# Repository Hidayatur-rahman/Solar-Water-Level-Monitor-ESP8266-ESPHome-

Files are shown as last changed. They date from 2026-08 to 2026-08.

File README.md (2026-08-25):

# Solar Water Level Monitor (ESP8266 + ESPHome)

A solar-powered water tank level monitoring system built around the ESP8266 (ESP-12E), designed in KiCad and running on ESPHome. It measures water level with an ultrasonic sensor, monitors battery current/voltage, and charges itself from a solar panel with a selectable-voltage MPPT charger.

## Features

- **Water level sensing** using an HC-SR04 ultrasonic distance sensor
- **Solar MPPT charging** via CN3791, with jumper-selectable input voltage (6V / 9V / 12V)
- **Battery current & voltage monitoring** using an INA219 sensor
- **1S Li-ion protection** (over-charge / over-discharge / over-current) using DW01A + FS8205A
- **5V boost converter** (MT3608) to power the ESP8266 and sensors from a single Li-ion cell
- **Deep sleep support** for low power consumption between readings
- **ESPHome integration** — no custom firmware needed, works directly with Home Assistant

## Hardware Overview


 




| Block | Component | Notes |
|---|---|---|
| MCU | ESP-12E (ESP8266) | Runs ESPHome |
| Water sensor | HC-SR04 | 5V supply, echo signal stepped down to 3.3V via voltage divider |
| Current/voltage sensor | INA219 | I2C, monitors battery current (charge & discharge) |
| Boost converter | MT3608 | Steps battery voltage (3.0–4.2V) up to 5V |
| Solar charger | CN3791 | MPPT buck charger, up to 4A, input jumper-selectable for 6V/9V/12V panels |
| Battery protection | DW01A + FS8205A | Standard 1S Li-ion protection circuit |
| Battery | 1x 18650 Li-ion | Not included on the board |

## Pin Connections (ESP-12E)

| Function | GPIO |
|---|---|
| I2C SDA (INA219) | GPIO4 |
| I2C SCL (INA219) | GPIO5 |
| HC-SR04 Trig | GPIO14 |
| HC-SR04 Echo (via divider) | GPIO12 |
| Deep sleep wake | GPIO16 → RST (via solder jumper) |

## Solar Panel Voltage Selection

The CN3791 MPPT tracking voltage is set by closing one solder jumper on the board.
| Panel | Target MPPT | R18  | | VMPPT |
| --- | ---: | ---: | ---: | ---: |
| **6 V**  | ~5,0 V | 200k | **68k** |  **4,75 V** |
| **9 V**  | ~8,0 V | 200k | **39k** |  **7,38 V** |
| **12 V** | ~10,2 V | 200k | **33k** |  **8,50 V** |

> Only close **one** jumper at a time.

## Getting Started

1. Flash the board with [ESPHome](https://esphome.io/), using the provided YAML configuration (`esphome/water-level-sensor.yaml`)
2. Connect the HC-SR04, battery, and solar panel
3. Set the solar jumper according to your panel's voltage
4. Add the device to Home Assistant via the ESPHome integration

## PCB

- Designed in KiCad, 2-layer, 60x60mm
- Gerber files and schematic are in the `/hardware` folder

## License

MIT — feel free to use, modify, and build upon this project.

## Disclaimer

This is a hobbyist/DIY project. Double-check battery polarity and solar jumper settings before powering on. No warranty is provided — build and use at your own risk.

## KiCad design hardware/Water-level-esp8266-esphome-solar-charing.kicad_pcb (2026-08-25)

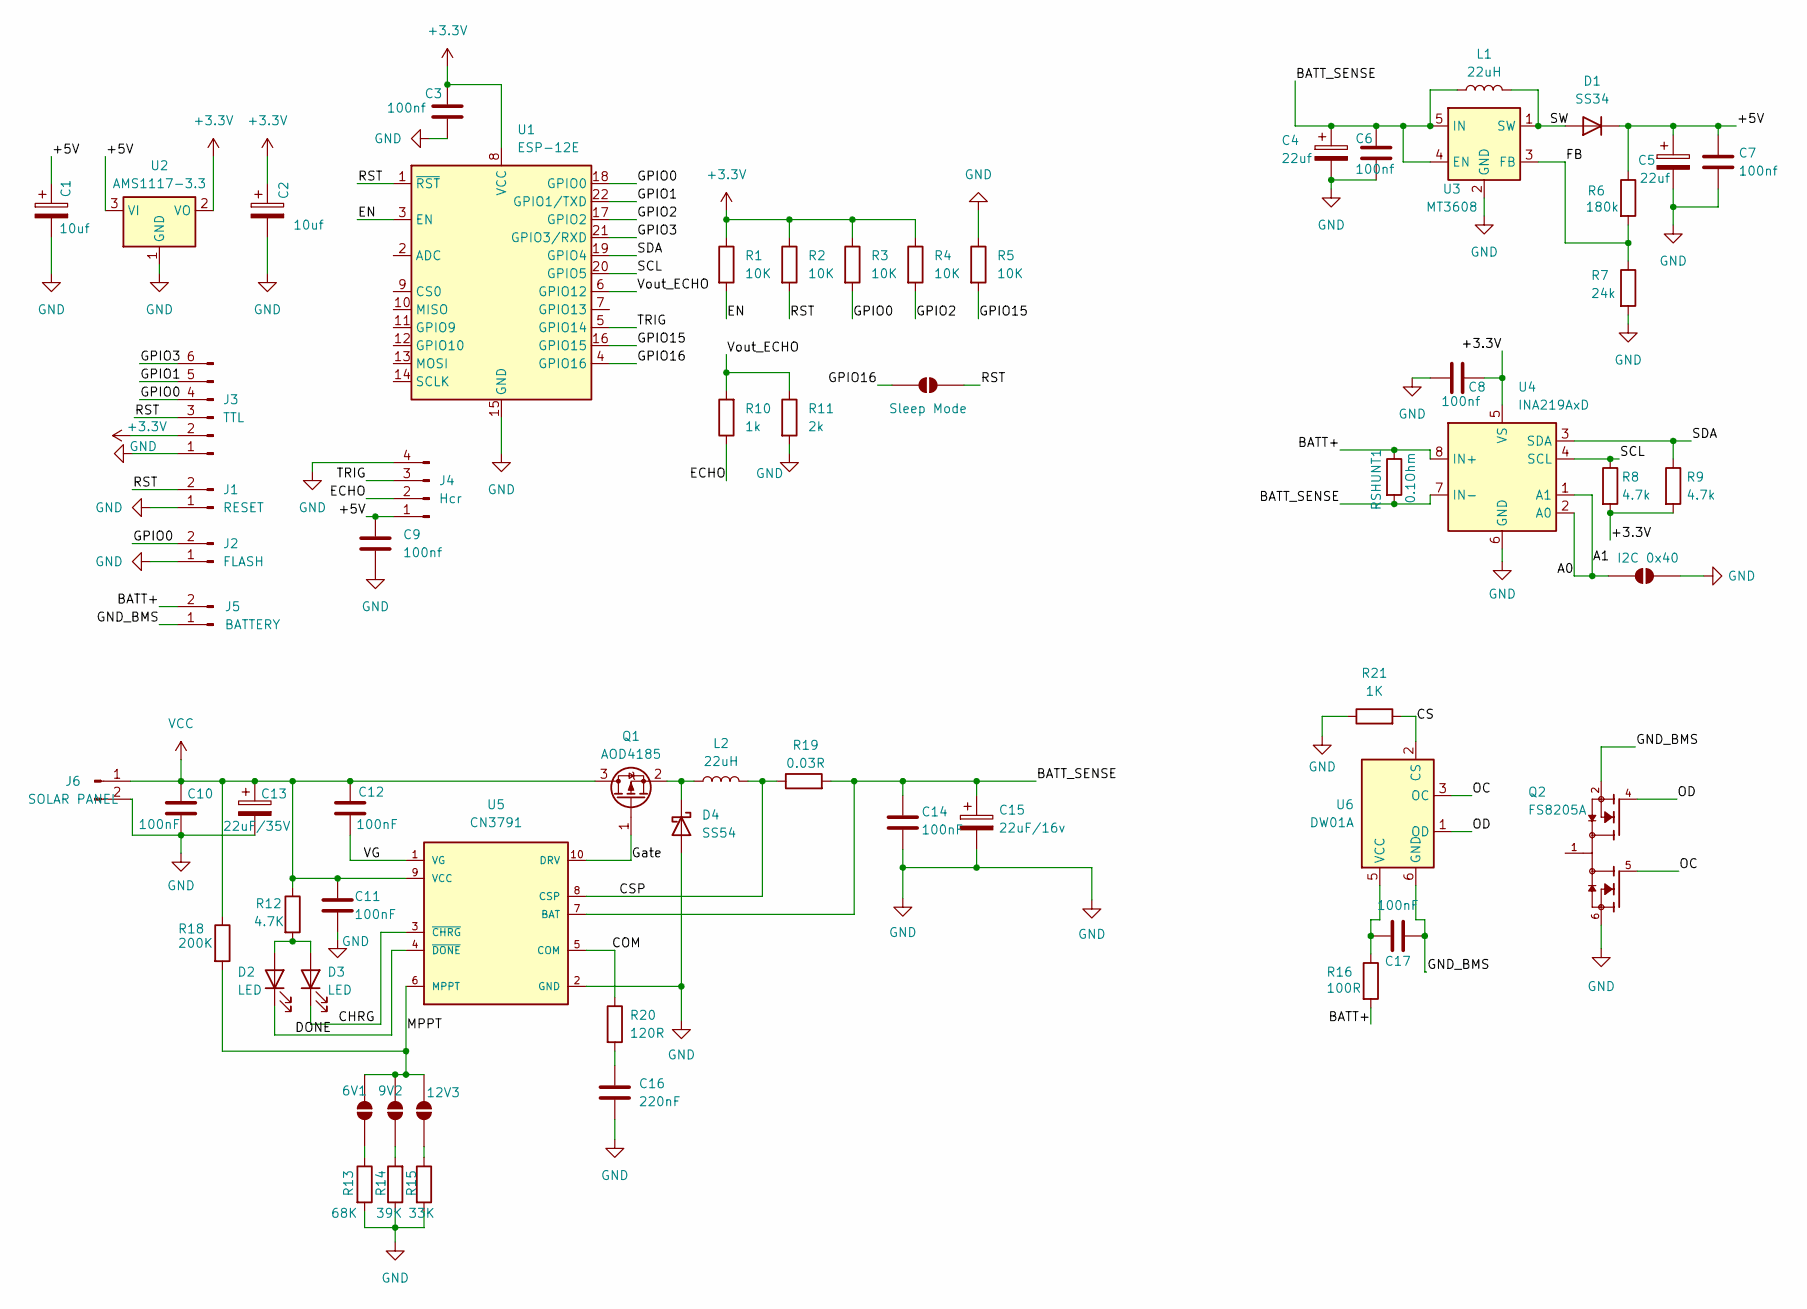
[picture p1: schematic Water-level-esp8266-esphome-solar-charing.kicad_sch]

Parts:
6V1, 9V2, 12V3: SolderJumper_2_Open; SolderJumper-2_P1.3mm_Open_RoundedPad1.0x1.5mm
C1, C2: 10uf; C_1206_3216Metric_Pad1.33x1.80mm_HandSolder
C3, C6, C7, C8, C9: 100nf; C_0603_1608Metric_Pad1.08x0.95mm_HandSolder
C4, C5: 22uf; C_1206_3216Metric_Pad1.33x1.80mm_HandSolder
C10, C11, C12, C14, C17: 100nF; C_0603_1608Metric_Pad1.08x0.95mm_HandSolder
C13: 22uF/35V; CP_Elec_8x6.9
C15: 22uF/16v; CP_Elec_8x6.9
C16: 220nF; C_0603_1608Metric_Pad1.08x0.95mm_HandSolder
D1: SS34; D_1206_3216Metric_Pad1.42x1.75mm_HandSolder
D2, D3: LED; LED_0805_2012Metric_Pad1.15x1.40mm_HandSolder
D4: SS54; D_SMA
J1: RESET; PinHeader_1x02_P2.54mm_Vertical
J2: FLASH; PinHeader_1x02_P2.54mm_Vertical
J3: TTL; PinHeader_1x06_P2.54mm_Vertical
J4: Hcr; PinHeader_1x04_P2.54mm_Vertical
J5: BATTERY; JST_PH_B2B-PH-K_1x02_P2.00mm_Vertical
J6: SOLAR PANEL; JST_PH_B2B-PH-K_1x02_P2.00mm_Vertical
JP1: Sleep Mode; SolderJumper-2_P1.3mm_Open_Pad1.0x1.5mm
JP2: I2C 0x40; SolderJumper-2_P1.3mm_Open_Pad1.0x1.5mm
L1: 22uH; L_Changjiang_FNR4030S
L2: 22uH; L_Changjiang_FXL1030
Q1: AOD4185; TO-252-2
Q2: FS8205A; SOP65P640X120-8N; PARTREV 1.7
R1, R2, R3, R4, R5: 10K; R_0805_2012Metric_Pad1.20x1.40mm_HandSolder
R6: 180k; R_0805_2012Metric_Pad1.20x1.40mm_HandSolder
R7: 24k; R_0805_2012Metric_Pad1.20x1.40mm_HandSolder
R8, R9: 4.7k; R_0805_2012Metric_Pad1.20x1.40mm_HandSolder
R10: 1k; R_0805_2012Metric_Pad1.20x1.40mm_HandSolder
R11: 2k; R_0805_2012Metric_Pad1.20x1.40mm_HandSolder
R12: 4.7K; R_0805_2012Metric_Pad1.20x1.40mm_HandSolder
R13: 68K; R_0805_2012Metric_Pad1.20x1.40mm_HandSolder
R14: 39K; R_0805_2012Metric_Pad1.20x1.40mm_HandSolder
R15: 33K; R_0805_2012Metric_Pad1.20x1.40mm_HandSolder
R16: 100R; R_0805_2012Metric_Pad1.20x1.40mm_HandSolder
R18: 200K; R_0805_2012Metric_Pad1.20x1.40mm_HandSolder
R19: 0.03R; R_2512_6332Metric_Pad1.40x3.35mm_HandSolder
R20: 120R; R_0805_2012Metric_Pad1.20x1.40mm_HandSolder
R21: 1K; R_0805_2012Metric_Pad1.20x1.40mm_HandSolder
RSHUNT1: 0.1Ohm; R_2512_6332Metric_Pad1.40x3.35mm_HandSolder
U1: ESP-12E
U2: AMS1117-3.3; SOT-223-3_TabPin2
U3: MT3608; SOT-23-6
U4: INA219AxD; SOIC-8_3.9x4.9mm_P1.27mm
U5: CN3791; CN3791_SSOP10
U6: DW01A; SOT-23-6

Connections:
+3.3V: C2.1, C3.1, C8.2, J3.2, R1.1, R2.1, R3.1, R4.1, R8.2, R9.2, U1.8 (VCC), U2.2 (VO), U4.5 (VS)
/+5V: C1.1, C5.1, C7.1, C9.1, D1.1 (K), J4.1, R6.1, U2.3 (VI)
/A0: JP2.2 (B), U4.1 (A1), U4.2 (A0)
/BATT+: J5.2, R16.2, RSHUNT1.1, U4.8 (IN+)
/BATT_SENSE: C4.1, C6.1, C14.1, C15.1, L1.1, R19.2, RSHUNT1.2, U3.4 (EN), U3.5 (IN), U4.7 (IN-), U5.7 (BAT)
/CHRG: D3.1 (K), U5.3 (~CHRG)
/COM: R20.1, U5.5 (COM)
/CS: R21.2, U6.2 (CS)
/CSP: L2.2, R19.1, U5.8 (CSP)
/DONE: D2.1 (K), U5.4 (~DONE)
/ECHO: J4.2, R10.1
/EN: R1.2, U1.3 (EN)
/FB: R6.2, R7.1, U3.3 (FB)
/GND_BMS: C17.2, J5.1, Q2.2, Q2.3, U6.6 (GND)
/GPIO0: J2.2, J3.4, R3.2, U1.18 (GPIO0)
/GPIO1: J3.5, U1.22 (GPIO1/TXD)
/GPIO2: R4.2, U1.17 (GPIO2)
/GPIO3: J3.6, U1.21 (GPIO3/RXD)
/GPIO15: R5.2, U1.16 (GPIO15)
/GPIO16: JP1.2 (B), U1.4 (GPIO16)
/Gate: Q1.1 (G), U5.10 (DRV)
/MPPT: 6V1.2 (B), 9V2.1 (A), 12V3.2 (B), R18.2, U5.6 (MPPT)
/OC: Q2.5, U6.3 (OC)
/OD: Q2.4, U6.1 (OD)
/RST: J1.2, J3.3, JP1.1 (A), R2.2, U1.1 (~RST)
/SCL: R8.1, U1.20 (GPIO5), U4.4 (SCL)
/SDA: R9.1, U1.19 (GPIO4), U4.3 (SDA)
/SW: D1.2 (A), L1.2, U3.1 (SW)
/TRIG: J4.3, U1.5 (GPIO14)
/VG: C12.2, U5.1 (VG)
/Vout_ECHO: R10.2, R11.1, U1.6 (GPIO12)
GND: C1.2, C2.2, C3.2, C4.2, C5.2, C6.2, C7.2, C8.1, C9.2, C10.2, C11.2, C13.2, C14.2, C15.2, C16.2, D4.2 (A), J1.1, J2.1, J3.1, J4.4, J6.2, JP2.1 (A), Q2.6, Q2.7, R5.1, R7.2, R11.2, R13.2, R14.1, R15.2, R21.1, U1.15 (GND), U2.1 (GND), U3.2 (GND), U4.6 (GND), U5.2 (GND)
unnamed: 6V1.1 (A), R13.1
unnamed: 9V2.2 (B), R14.2
unnamed: 12V3.1 (A), R15.1
unnamed: C16.1, R20.2
unnamed: D2.2 (A), D3.2 (A), R12.2
unnamed: D4.1 (K), L2.1, Q1.2 (S)
unnamed: Q2.1, Q2.8
unnamed: C17.1, R16.1, U6.5 (VCC)
VCC: C10.1, C11.1, C12.1, C13.1, J6.1, Q1.3 (D), R12.1, R18.1, U5.9 (VCC)

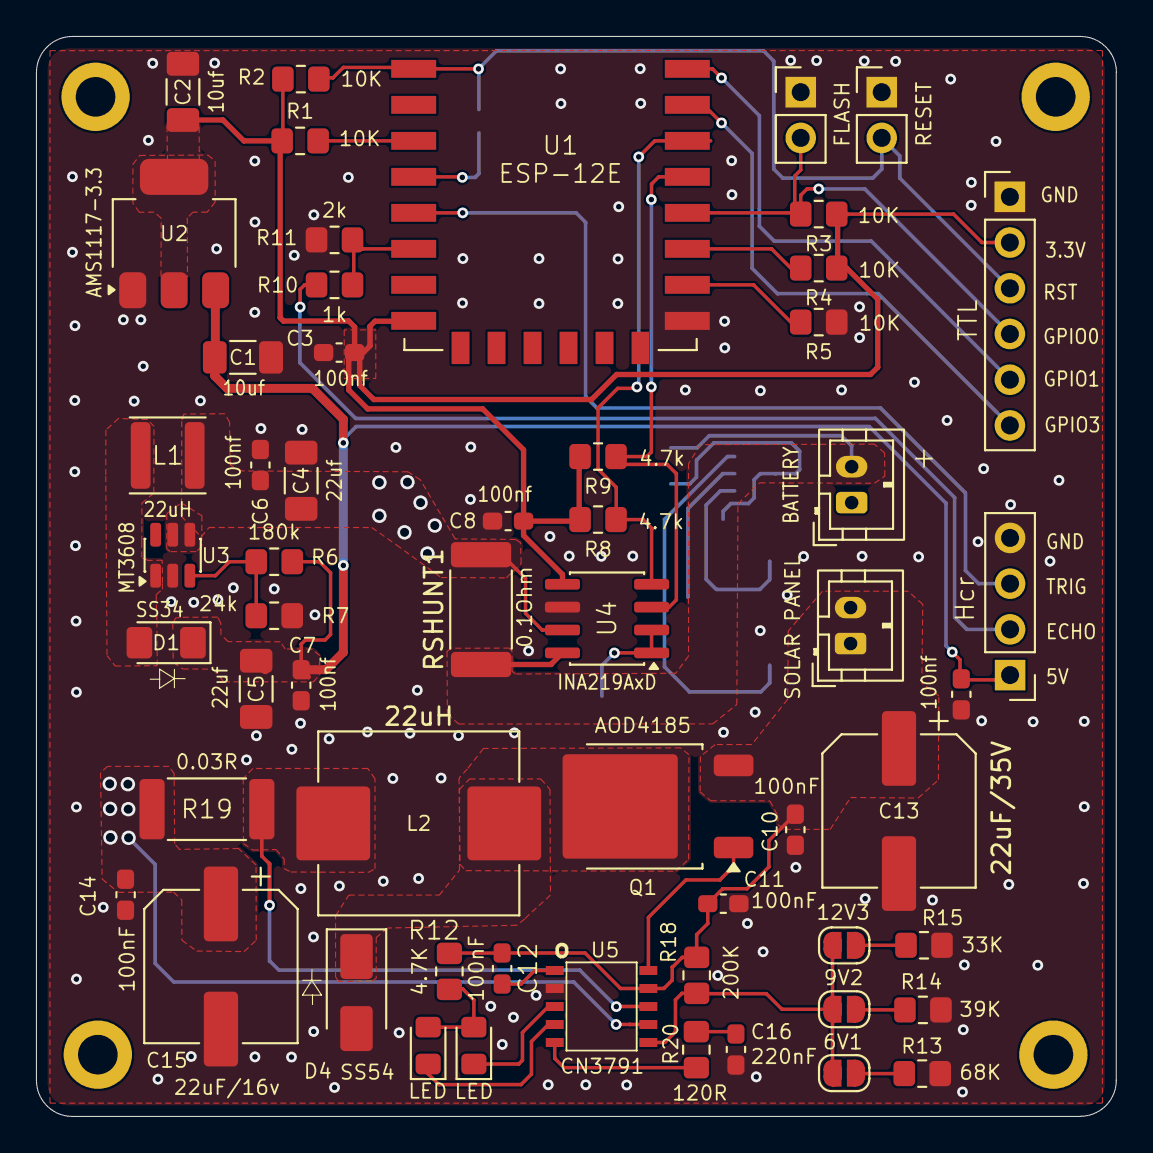
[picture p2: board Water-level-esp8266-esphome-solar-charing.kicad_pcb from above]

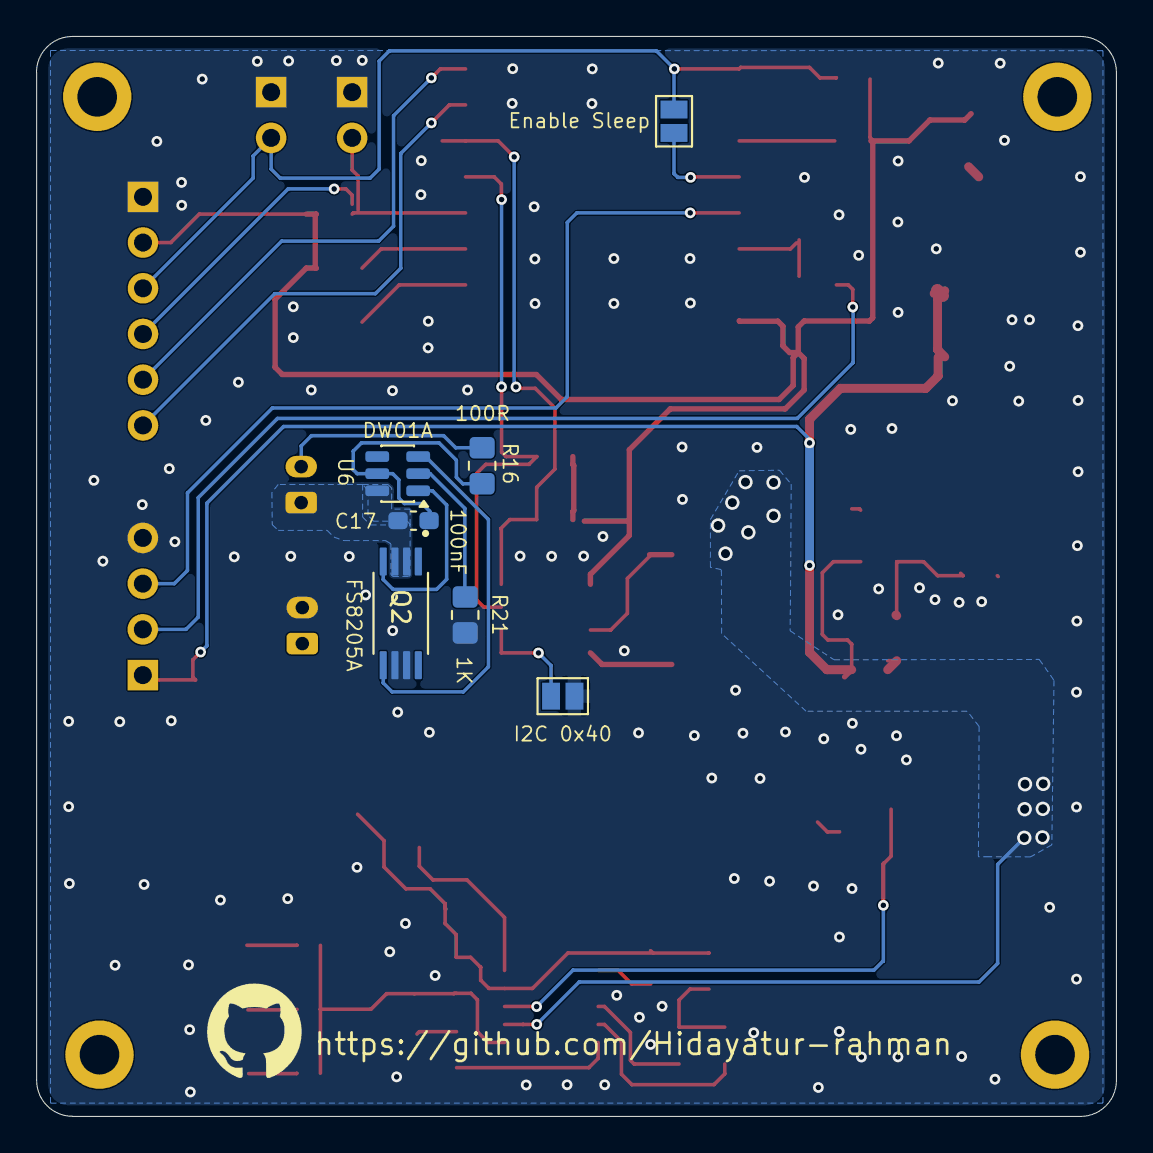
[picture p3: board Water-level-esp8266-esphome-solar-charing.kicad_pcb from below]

Board: 2 copper layers, 60.0 x 60.0 mm, 63 parts (7 on the bottom side), 41 nets.

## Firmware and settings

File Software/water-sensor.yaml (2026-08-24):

esphome:
  name: water-sensor-tandon
  friendly_name: Water Sensor Tandon

esp8266:
  board: nodemcuv2

# Enable logging
logger:
  level: DEBUG

# Enable Home Assistant API
api:
  # encryption:
  #   key: "00000"

ota:
  platform: esphome

wifi:
  ssid: !secret wifi_ssid
  password: !secret wifi_password
  min_auth_mode: WPA2
  fast_connect: true
  power_save_mode: none
  reboot_timeout: 5min

  on_connect:
    - light.turn_on: wifi_led

  on_disconnect:
    - light.turn_off: wifi_led

deep_sleep:
  id: deep_sleep_control

time:
  - platform: sntp
    id: waktu_sistem
    timezone: Asia/Makassar

output:
  - platform: gpio
    pin:
      number: GPIO2
      inverted: true
    id: led_wifi_output

light:
  - platform: binary
    name: "LED WiFi"
    output: led_wifi_output
    id: wifi_led


# =========================
# GLOBAL VARIABLE
# =========================
globals:

  - id: baterai_lemah_v
    type: float
    restore_value: no
    initial_value: '3.00'

i2c:
  sda: GPIO4
  scl: GPIO5
  scan: true

binary_sensor:
  - platform: homeassistant
    name: "Status Mesin Air"
    id: mesin_air_ha
    entity_id: switch.mesin_air_water_pump_relay_2

# === SENSOR ===
sensor:
  # ---- INA219 Battery Monitoring ----
  - platform: ina219
    address: 0x40
    shunt_resistance: 0.1 ohm
    update_interval: 10s

    current:
      name: "Arus Baterai Kost"
      id: arus_baterai_kost
      unit_of_measurement: "A"
      accuracy_decimals: 3
      filters:
        - median:
            window_size: 5
            send_every: 3
        - exponential_moving_average:
            alpha: 0.2

    bus_voltage:
      name: "Tegangan Baterai Kost"
      id: tegangan_baterai_kost
      unit_of_measurement: "V"
      accuracy_decimals: 2
      filters:
        - median:
            window_size: 5
            send_every: 3
        - exponential_moving_average:
            alpha: 0.2

    power:
      name: "Daya Kost"
      unit_of_measurement: "W"
      accuracy_decimals: 2
      filters:
        - median:
            window_size: 5
            send_every: 3
        - exponential_moving_average:
            alpha: 0.2

# ---- Ultrasonic Water Level (D5=GPIO14 trigger, D6=GPIO12 echo) ----
  - platform: ultrasonic
    trigger_pin: GPIO14
    echo_pin: GPIO12
    name: "Water Level Kost"
    id: persen_air
    update_interval: 10s
    unit_of_measurement: "%"
    accuracy_decimals: 1
    filters:
      - filter_out: nan
      - median:
          window_size: 5
          send_every: 3
          send_first_at: 3
      - exponential_moving_average:
          alpha: 0.2
          send_every: 1
      - lambda: |-
          const float low_level = 1.30;   // permukaan air saat kosong
          const float high_level = 0.30;  // permukaan air saat penuh

          if (x > low_level) {
            return 0.0;
          } else if (x < high_level) {
            return 100.0;
          } else {
            return (1.0 - (x - high_level) / (low_level - high_level)) * 100.0;
          }


  # ---- Persentase Baterai dari bus_voltage INA219 ----
  - platform: template
    name: "Persentase Baterai Kost"
    id: persentase_baterai_kost
    unit_of_measurement: "%"
    accuracy_decimals: 0
    update_interval: 10s
    lambda: |-
      if (!id(tegangan_baterai_kost).has_state() || isnan(id(tegangan_baterai_kost).state)) return {};
      float voltage = id(tegangan_baterai_kost).state;
      float min_v = id(baterai_lemah_v);
      float max_v = 4.2;   // baterai penuh
      float pct = ((voltage - min_v) / (max_v - min_v)) * 100.0;
      if (pct > 100) pct = 100;
      if (pct < 0) pct = 0;
      return pct;
    filters:
      - median:
          window_size: 5
          send_every: 3
          send_first_at: 3
      - exponential_moving_average:
          alpha: 0.2
          send_every: 1
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

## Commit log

2026-08-24 Refine solar charger voltage options in README
    Updated solar charger input voltage options in the README.
2026-08-24 Update resistor references in voltage selection table
2026-08-24 Add water sensor configuration for ESPHome
    This YAML configuration sets up a water sensor with various features including WiFi connectivity, deep sleep logic, and multiple sensors for battery and water level monitoring.
